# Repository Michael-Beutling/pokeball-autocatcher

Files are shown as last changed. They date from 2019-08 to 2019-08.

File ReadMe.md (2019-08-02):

# Pokeball Auto Catcher

## Problem & goal

To perform a auto catch with a pokeball plus you have normally two options:

* Warp a rubber band and a coin or the safety band from the ball around the ball so the red button is permanently pressed.
	* pro: simple, reversible, cheap, Pokeball is still as controller useable
	* con: tricky to wrap, drains after a session (1h) the battery 
*  Wire the vibration to the button.
	* pro: simple, cheap (when you have a solder iron and a wire :)
	* con: The Vibration unit work at a voltage of 5V and the button input has only 1.8 V, to use the Pokeball as controller You must disable the vibration function before the mod.

We need a third option which fit the following requirements:

* usable as controller without restrictions
* less tricky
* more exensive as a rubber band or a wire
* hard to install 
* and more complex

## Solderpoints
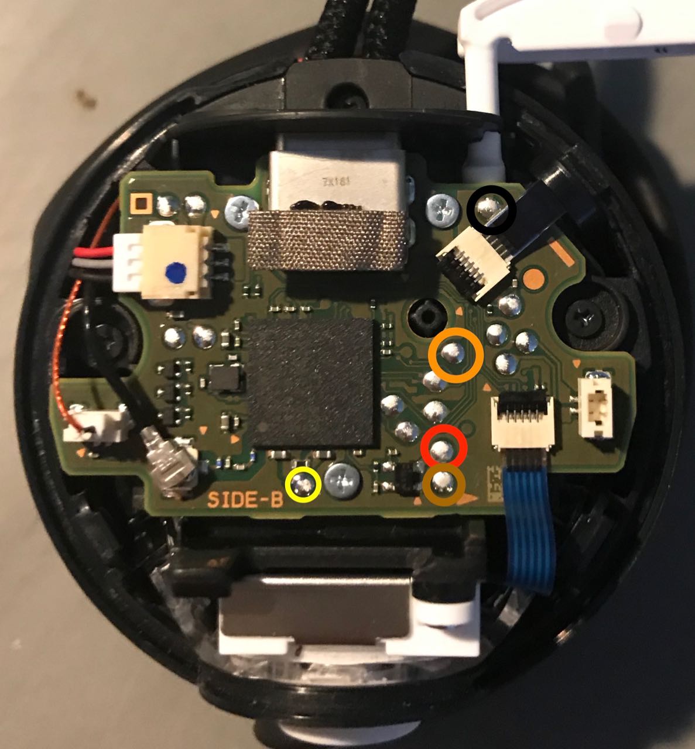
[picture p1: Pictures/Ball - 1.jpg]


Color | Signal
------|-------
black | Ground 
orange | Top button 
red | 1.8 V Vcc
yellow | 1.2 V (core voltage?)
brown | 5 V (LEDs & vibration unit)

## Wiring
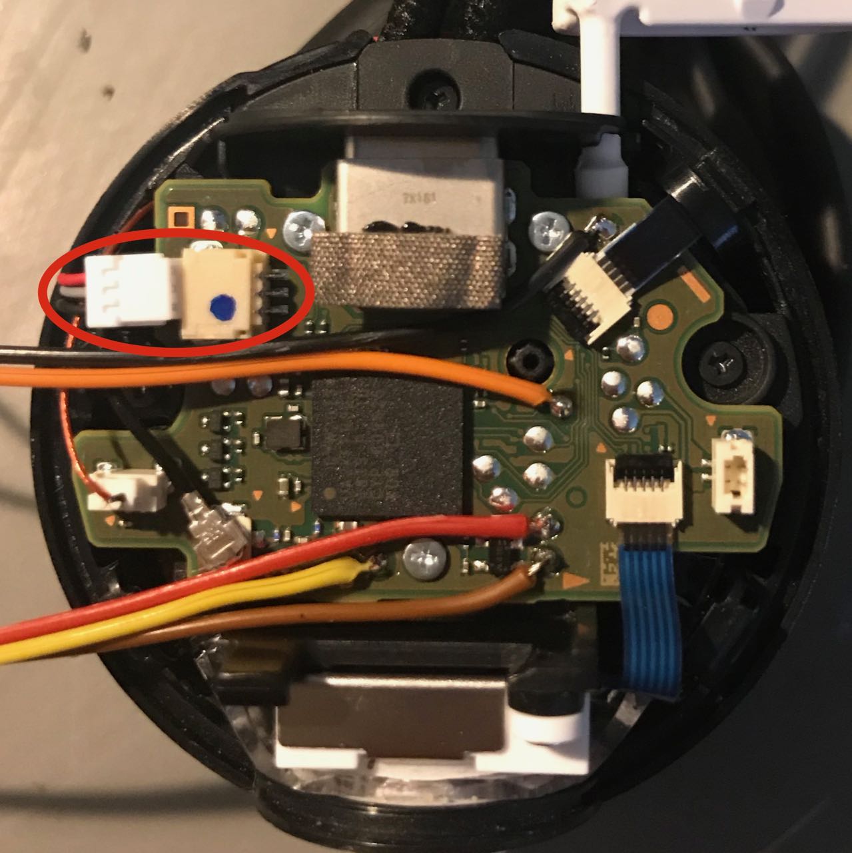
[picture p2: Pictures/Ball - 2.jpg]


Don't forget to unplug the battery, before You soldering!

## Finished mod
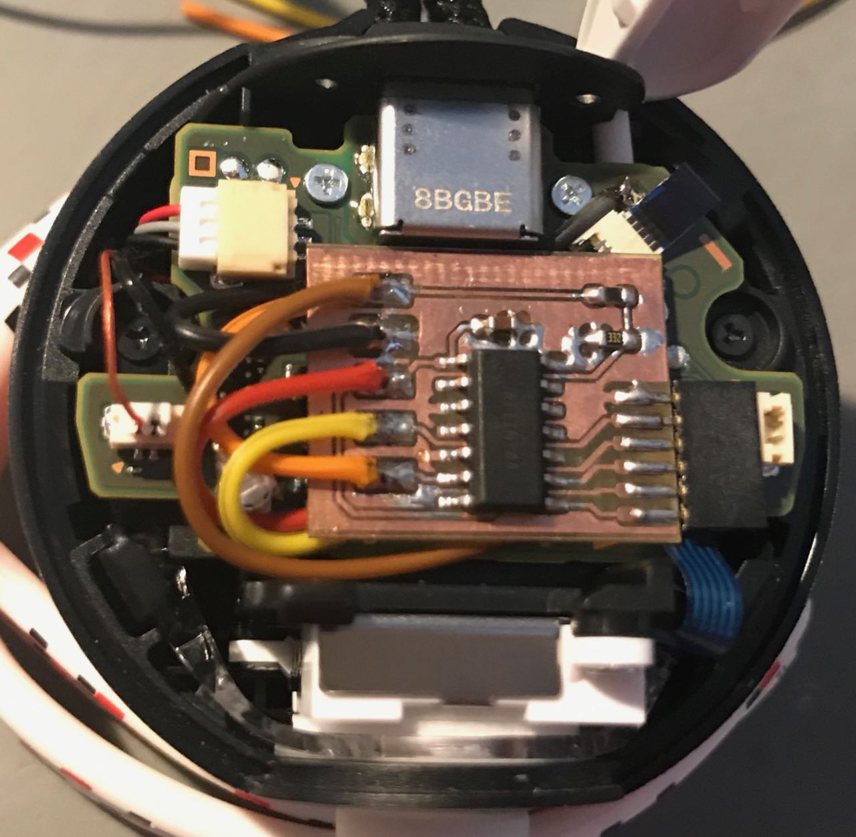
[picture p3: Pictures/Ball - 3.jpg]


## How it works

The attiny measure with the analog comparator the core(?) voltage and the voltage for the LED and vibration unit. If the ball is turned on with the top button (press more as 120 ms), then the auto catch function is active. Every time when the voltage for the LED and vibration unit is turned on, the attiny "press" the button for 1 second. 

## Project status
Its work for me and my family -> Project closed for me.
Open points:
* clean up the pcb:
	* i think the ground plane and the 1V8 route in the near of the wiring is a bad idea
	*  sort the wire solder points in the order of wire from the ball-> less wire crossing 
	*  reorder the attiny pins, see point above
*  the attiny need 70 µs to turn on the bandgap reference which is realized with a delay function (actual 100 µs), a timer based solution could save more power?

## Bill of material
* 1x 6 pin female Connector pitch 1.27 mm (50 mil), I use Connfly Receptacles (standard) No. of rows: 1 Pins per row: 6 DS1065-01-1*6S8BV
* 1x 6 pin male connector pitch 1.27 mm (50 mil), BKL Electronic Pin strip (standard) No. of rows: 1 Pins per row: 6 10120623
* 2x3 pin male connector (AVR ISP standard), W & P Products 137-06-1-00-2 Tray Terminal Strip Number of pins: 2 x 3 mm
* PCB material Photo-coating Positive single sided 35 µm Material thickness **0.5 mm**, it's really narrow in the ball.
* Atmel ATTiny441-SSU (SOIC-14)
* Resistor 0805 10k
* Resistor 0805 3.3k
* Capacitor 0805 10k

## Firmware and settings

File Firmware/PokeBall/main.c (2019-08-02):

/*
* PokeBall.c
*
* Created: 02.07.19 14:19:49
* Author : micha
*/

#include <avr/io.h>
#include <avr/interrupt.h>
#include <avr/sleep.h>
#include <avr/power.h>
#include <avr/wdt.h>
#include <avr/cpufunc.h>
//#include <avr/fuse.h>
// 8 MHz / 8
#define F_CPU 1000000UL
#include <util/delay.h>

FUSES =
{
	.extended =0xff,
	.high = 0xdf,
	.low = 0x42,
};



// watchdog 120 ms
#define CYCLETIME (1000/120)

/* Fuses
ULPOSCSEL = ULPOSC_32KHZ
BODPD = BOD_DISABLED
BODACT = BOD_DISABLED
SELFPRGEN = [ ]
RSTDISBL = [ ]
DWEN = [ ]
SPIEN = [X]
WDTON = [ ]
EESAVE = [ ]
BODLEVEL = <none selected>
CKDIV8 = [X]
CKOUT = [ ]
SUT_CKSEL = INTRCOSC_8MHZ_6CK_16CK_16MS

EXTENDED = 0xFF (valid)
HIGH = 0xDF (valid)
LOW = 0x42 (valid)


*/

// SW-HW Interface

// Button (6)
#define PIN_BUTTON _BV(PINA7)

// new Debug PINs A4/A5/A6 (9, 8, 7)
// ADC3 (10) 1.2V (cpu core?)
// ADC11 (2) 5.0V (led/vib voltage)

enum ballState_t {
    BALL_RESET=0,              // power on reset, reset button
    BALL_OFF=1,                // Core off
    BALL_ON=2,                 // core on, normal operation
    BALL_AUTOCATCH_WAIT=3,     // autocatch start, button must released
    BALL_AUTOCATCH_PRESSED=4,  // 5v on, button press
    BALL_AUTOCATCH_STANDBY=5,  // 5v off, release button
    BALL_AUTOCATCH_STANDBY2=6, // 5v measure, release button
    BALL_DEBUG_SYNC=7          // for debugging
} ballState;

inline void pressButton() {
    DDRA|=PIN_BUTTON;
}

inline void releaseButton() {
    DDRA&=~PIN_BUTTON;
}

inline void initButton() {
    releaseButton();
    // prepare low level
    PORTA&=~PIN_BUTTON;
}

inline void initDebugPins() {
    // Pin PA0/1/2 debug pins
    DDRA|=_BV(DDRA4)|_BV(DDRA5)|_BV(DDRA6);
}

inline void setDebugPins(enum ballState_t value) {
    PORTA=(PORTA&~(_BV(DDRA4)|_BV(DDRA5)|_BV(DDRA6)))|(((char)value&7)<<DDRA4);
}

inline void setPowerSavingOn() {
    set_sleep_mode(SLEEP_MODE_PWR_DOWN); // set power down mode, only watchdog
    power_all_disable();
    DIDR0=(char)~(PIN_BUTTON);
    DIDR1=0;
}

inline  char readButton() {
    return !(PINA&PIN_BUTTON);
}

void startComparator() {
    power_adc_enable();
    //ADMUXA=3; // ADC3 (core)
    ACSR0A=_BV(ACPMUX2); // 
    ACSR0B=_BV(ACNMUX0); // p=bandgap, n= adc muxer
    _delay_us(100.0);  // todo does a timer interrupt saving power?
}

inline void stopComparator() {
    power_adc_disable();
	ACSR0A=_BV(ACD0);
}

 inline char readCore() {
    ADMUXA=3; // ADC3 (core)
    _NOP(); // wait for comparator
    _NOP();
    _NOP();
    return!(ACSR0A&_BV(ACO0));
}

 inline char read5V() {
    ADMUXA=11; // ADC11 (5v for leds and vib)
    _NOP(); // wait for comparator
    _NOP();
    _NOP();
    return!(ACSR0A&_BV(ACO0));
}



ISR(WDT_vect) {
    static char stateTimer=CYCLETIME;
	char isCore;
	char is5V;
	char isButton;
	
    WDTCSR |= _BV(WDIE);
    setDebugPins(BALL_DEBUG_SYNC); // all debug pins up

    setDebugPins(BALL_DEBUG_SYNC);
    
	startComparator();  // read inputs
	isCore=readCore();
	is5V=read5V();
	isButton=readButton();
	stopComparator();
	
    setDebugPins(BALL_RESET); // all debug pins down

    switch(ballState) {
    case BALL_RESET:
        if(stateTimer) {
            if(!isButton) {
                stateTimer--;
            }
        } else {
            ballState=BALL_OFF;
        }
        break;
    case BALL_OFF:
        if(isCore) {
            ballState=isButton?BALL_AUTOCATCH_WAIT:BALL_ON;
            stateTimer=CYCLETIME;
        }
        break;
    case BALL_ON:
        if(!isCore) {
            ballState=BALL_OFF;
        } else {
            if(stateTimer) {  // manage periodic wake ups, every minute for ~600 ms
                stateTimer--;
                if(isButton) {
                    ballState=BALL_AUTOCATCH_WAIT;
                    stateTimer=CYCLETIME;
                }
            }
        }
        break;
    case BALL_AUTOCATCH_WAIT:
        if(!isCore) {
            ballState=BALL_OFF;
        } else {
            if(isButton) { // button MUST released for connection
                stateTimer=CYCLETIME;
            } else {
                if(stateTimer) {
                    stateTimer--;
                } else {
                    ballState=BALL_AUTOCATCH_STANDBY;
                }
            }
        }
        break;
    case BALL_AUTOCATCH_STANDBY:
        if(!isCore) {
            ballState=BALL_OFF;
        } else {
	        if(is5V) { //Vib&LEDs on?
		        ballState=BALL_AUTOCATCH_PRESSED;
			    pressButton();
				stateTimer=CYCLETIME;
			}
		}
        break;
    case BALL_AUTOCATCH_PRESSED:
        if(!is5V) {
            ballState=BALL_AUTOCATCH_STANDBY;
            releaseButton();
        }else{
			// limit to 1 s
			if(stateTimer){
				stateTimer--;
			}else{
				releaseButton();
			}
		}
        break;
    default:
        // something going wrong
        releaseButton();
        for(;;); // wait until watchdog reset
        break;
    }

    setDebugPins(ballState);
}

inline void initWatchdog() {
    MCUSR &= ~(1<<WDRF);
    cli();
    WDTCSR |= _BV(WDE)|_BV(WDIE);
    WDTCSR = WDTO_120MS;
    // enable watchdog interrupt only mode
    WDTCSR |= _BV(WDIE);
}


int main(void) {

    initWatchdog();
    initDebugPins();
    initButton();

    setPowerSavingOn();

    ballState=BALL_RESET;  // state after reset

    sleep_enable();
    sei();

    for(;;) {
        sleep_cpu(); // Snorlax is my guru
    }

}
